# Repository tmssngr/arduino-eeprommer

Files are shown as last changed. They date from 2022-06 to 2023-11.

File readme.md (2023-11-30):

# Arduino-Shield to flash EEPROMs

This is an Arduino shield that can be used to read or flash EEPROMs.
I've successfully flashed 28C16 and 28C64.

## Hardware
The schematic you can find [here](kicad/EPROM-Shield.pdf).
It has been created with KiCad 5.1.12.

The 74'595 shift registers are used to set the address lines A0-A12, /CS, /OE and /WE.
The address lines A13 and A14 for 28C128 or 28C256 are only available through jumpers, so only up to 8kB could be flashed in one row.

The EEPROMs data pins are connected via resistors to the arduino pins D0-D7 to prevent problems if the EEPROM and the Arduino accessing these pins as output.
For those arduino boards that use pins D0 and D1 for serial communication, you can use AD0 and AD1 instead.
In that case omit the resistors to D0 and D1, install those to AD0 and AD1, and change the constants `PIN_D0` and `PIN_D1` at the beginning of the [Eprommer595.ino](arduino/Eprommer595/Eprommer595.ino).

Note, you need to solder the pin headers onto the bottom side (in contrast to the below 3D view).

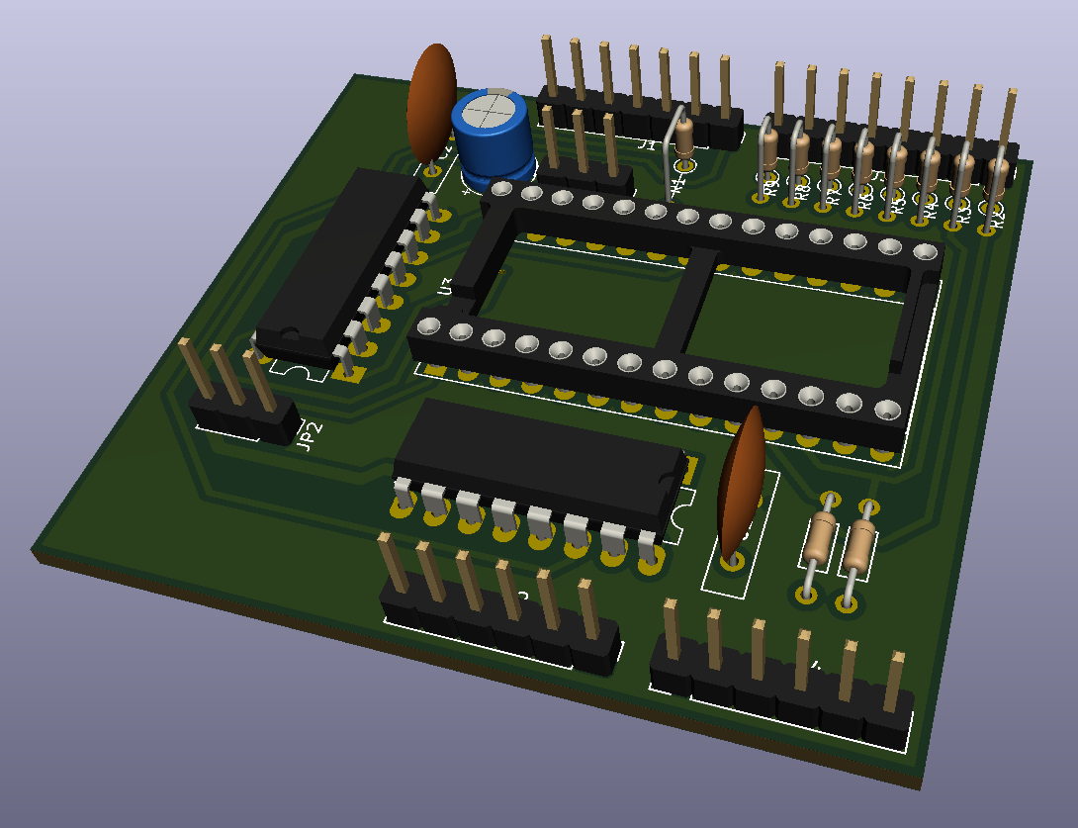
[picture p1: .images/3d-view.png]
3D-View


## Software
For simplicity the data to flash should be provided as array content (see [data_jute6k_video.h](arduino/Eprommer595/data_jute6k_video.h)).
Any output is provided over serial communication (9600 baud).

## Todo
- reserve more space around EEPROM to be able to mount a ZIF socket

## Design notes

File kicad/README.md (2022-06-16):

# EEPROMmer as Arduino Shield
This is my first attempt to create am EEPROMmer in the form of an Arduino shield.

## Alternative Approaches:
- Arduino-Mega-based: https://github.com/bmpc/arduino_eeprom_programmer
- Very good explanation of steps from breadboard: https://www.youtube.com/watch?v=K88pgWhEb1M

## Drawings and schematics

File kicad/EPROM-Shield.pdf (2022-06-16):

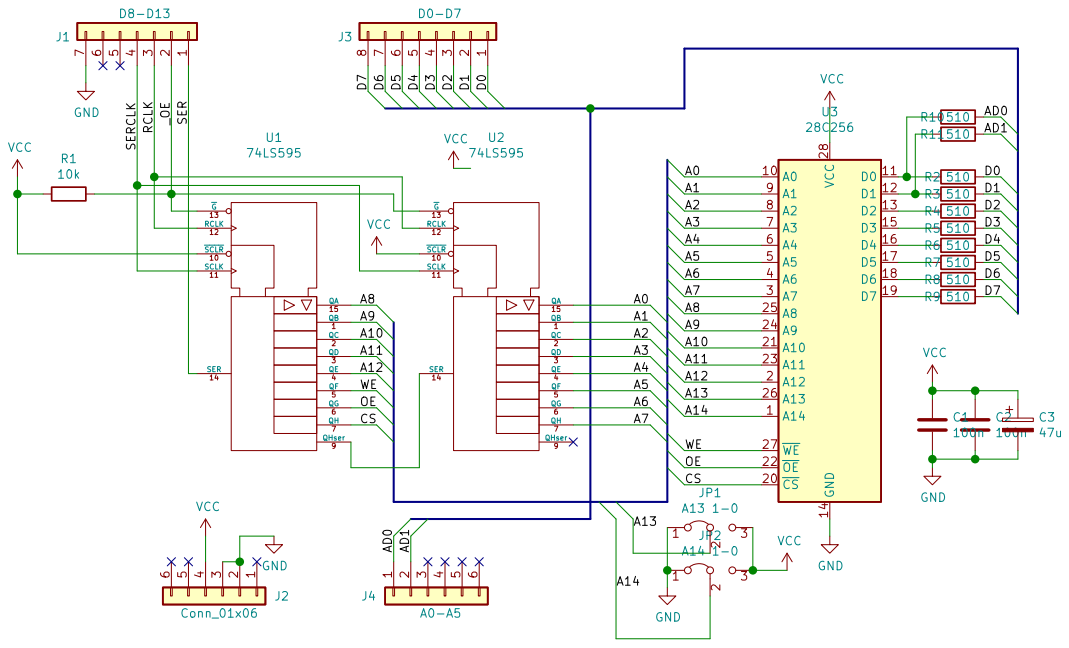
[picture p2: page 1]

Id: 1/1 Title: File: EPROM-Shield.sch Sheet: /

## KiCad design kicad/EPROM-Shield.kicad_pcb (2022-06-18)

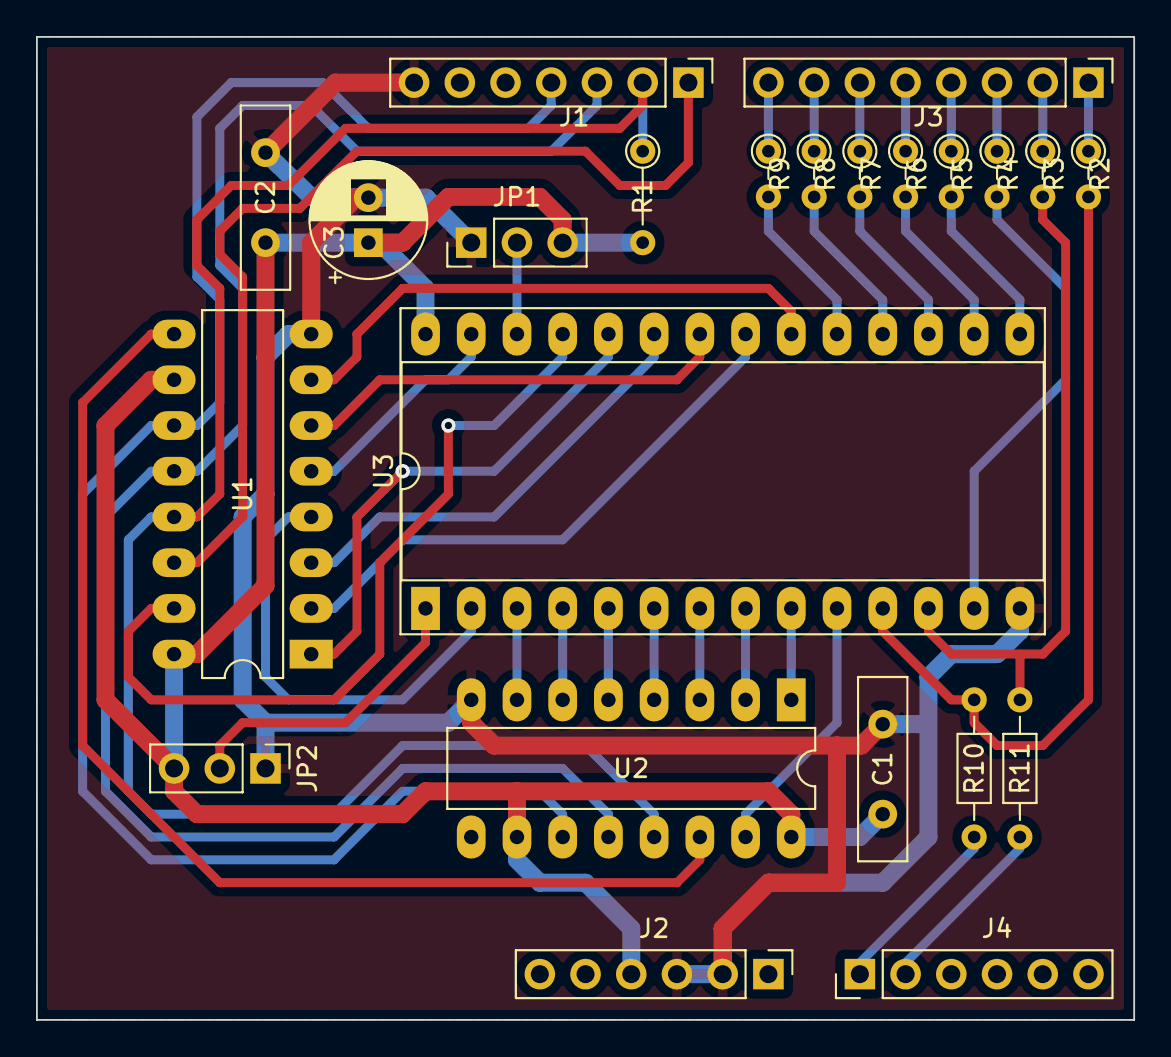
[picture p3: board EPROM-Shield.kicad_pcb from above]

Board: 2 copper layers, 61.0 x 54.6 mm, 23 parts (0 on the bottom side), 43 nets.

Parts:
C1, C2: 100n; C_Disc_D10.0mm_W2.5mm_P5.00mm
C3: 47u; CP_Radial_D6.3mm_P2.50mm
J1: D8-D13; PinHeader_1x07_P2.54mm_Vertical
J2: Conn_01x06; PinHeader_1x06_P2.54mm_Vertical
J3: D0-D7; PinHeader_1x08_P2.54mm_Vertical
J4: A0-A5; PinHeader_1x06_P2.54mm_Vertical
JP1: A13 1-0; PinHeader_1x03_P2.54mm_Vertical
JP2: A14 1-0; PinHeader_1x03_P2.54mm_Vertical
R1: 10k; R_Axial_DIN0204_L3.6mm_D1.6mm_P5.08mm_Vertical
R2, R3, R4, R5, R6, R7, R8, R9: 510; R_Axial_DIN0204_L3.6mm_D1.6mm_P2.54mm_Vertical
R10, R11: 510; R_Axial_DIN0204_L3.6mm_D1.6mm_P7.62mm_Horizontal
U1, U2: 74LS595; DIP-16_W7.62mm_LongPads
U3: 28C256; DIP-28_W15.24mm_Socket_LongPads

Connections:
/A0: U2.15, U3.10
/A1: U2.1, U3.9
/A2: U2.2, U3.8
/A3: U2.3, U3.7
/A4: U2.4, U3.6
/A5: U2.5, U3.5
/A6: U2.6, U3.4
/A7: U2.7, U3.3
/A8: U1.15, U3.25
/A9: U1.1, U3.24
/A10: U1.2, U3.21
/A11: U1.3, U3.23
/A12: U1.4, U3.2
/A13: JP1.2, U3.26
/A14: JP2.2, U3.1
/AD0: J4.1, R10.1
/AD1: J4.2, R11.1
/CS: U1.7, U3.20
/D0: J3.1, R2.1
/D1: J3.2, R3.1
/D2: J3.3, R4.1
/D3: J3.4, R5.1
/D4: J3.5, R6.1
/D5: J3.6, R7.1
/D6: J3.7, R8.1
/D7: J3.8, R9.1
/OE: U1.6, U3.22
/RCLK: J1.3, U1.12, U2.12
/SER: J1.1, U1.14
/SERCLK: J1.4, U1.11, U2.11
/WE: U1.5, U3.27
/_OE: J1.2, R1.1, U1.13, U2.13
GND: C1.2, C2.2, C3.2, J1.7, J2.2, J2.3, JP1.1, JP2.1, U1.8, U2.8, U3.14
unnamed: R4.2, U3.13
unnamed: R5.2, U3.15
unnamed: R6.2, U3.16
unnamed: R7.2, U3.17
unnamed: R8.2, U3.18
unnamed: R9.2, U3.19
unnamed: R2.2, R10.2, U3.11
unnamed: R3.2, R11.2, U3.12
unnamed: U1.9, U2.14
VCC: C1.1, C2.1, C3.1, J2.4, JP1.3, JP2.3, R1.2, U1.10, U1.16, U2.10, U2.16, U3.28

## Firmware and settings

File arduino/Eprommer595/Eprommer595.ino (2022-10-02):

#include "serial_utils.h"
#include "data_jute6k_video.h"
//#include "data_ub8830_jute6k.h"
//#include "data_ub8830_jute6k_modified_keyboard.h"

const uint8_t PIN_SER = 8;
const uint8_t PIN_OE = 9;
const uint8_t PIN_RCLK = 10;
const uint8_t PIN_SERCLK = 11;
const uint8_t PIN_D0 = 0;
const uint8_t PIN_D1 = 1;
const uint8_t PIN_D2 = 2;
const uint8_t PIN_D3 = 3;
const uint8_t PIN_D4 = 4;
const uint8_t PIN_D5 = 5;
const uint8_t PIN_D6 = 6;
const uint8_t PIN_D7 = 7;

const uint8_t DEBUG = 0;

void setup() {
  pinMode(PIN_SER, OUTPUT);
  pinMode(PIN_OE, OUTPUT);
  pinMode(PIN_RCLK, OUTPUT);
  pinMode(PIN_SERCLK, OUTPUT);
  setDataMode(INPUT);
  setAddress_WE_OE_CS(0, 1, 1, 1);

  Serial.begin(9600);
  while (!Serial) {
    // wait
  }

  Serial.println("start" );

  // uncomment the next 2 lines to write and verify the imported DATA array
  //writeData();
  //verifyData();

  printRomContent(0, 0x2000);
}

void loop() {
}

void testWriteRead() {
  for (int i = 0; i < 0x800; i++) {
    write(i, 0xff);
  }

  printRomContent(0, 0x800);
}

uint8_t readData(int address) {
  return pgm_read_byte(DATA + address);
}

void writeData() {
  Serial.println("Writing");

  for (int i = 0; i < DATA_LENGTH; i++) {
    if (i % 16 == 0) {
      if (i > 0) {
        Serial.println();
      }
      serialPrintHex(i, 4);
      Serial.print(" ");
    }

    writeAndVerify(i, readData(i));
  }
}

void verifyData() {
  Serial.println("Verifying");

  int errors = 0;
  for (int i = 0; i < DATA_LENGTH; i++) {
    if (i % 16 == 0) {
      if (i > 0) {
        Serial.println();
      }
      serialPrintHex(i, 4);
    }

    uint8_t readValue = read(i);
    uint8_t expectedValue = readData(i);
    if (readValue != expectedValue) {
      Serial.print(" expected ");
      serialPrintHex(expectedValue, 2);
      Serial.print(" at ");
      serialPrintHex(i, 4);
      Serial.print(", but read ");
      serialPrintHex(readValue, 2);
      Serial.println();
      errors++;
    }

    if (i % 16 == 15 || i + 1 == DATA_LENGTH) {
      Serial.println(" OK");
    }
  }

  if (errors == 0) {
    Serial.println("No errors :)");
  }
  else {
    Serial.print(errors);
    Serial.println(" errors :(");
  }
}

void printRomContent(int start, int end) {
  for (int i = start; i < end; i++) {
    if (i % 16 == 0) {
      if (i > 0) {
        Serial.println();
      }
      serialPrintHex(i, 4);
    }

    Serial.print(" ");

    uint8_t value = read(i);
    serialPrintHex(value, 2);
  }
  Serial.println();
}

void writeAndVerify(uint16_t address, uint8_t value) {
  if (DEBUG == 1) {
    serialPrintHex(address, 4);
    Serial.print(":=");
    serialPrintHex(value, 2);
    Serial.println(">");
  }

  uint8_t existingValue = read(address);
  if (existingValue == value) {
    Serial.print(" ");
    return;
  }

  write(address, value);
  delay(10);

  for (int i = 0; i < 10; i++) {
    uint8_t readValue = read(address);
    if (readValue == value) {
      return;
    }

    Serial.print(".");
  }

  Serial.print("FAILURE at ");
  serialPrintHex(address, 4);
  Serial.print(" - aborting");
  while (true) {
  }
}

void write(uint16_t address, uint8_t value) {
  setAddress_WE_OE_CS(address, 1, 1, 1);
  // In the XL1816 the write cycle is initiated by applying 
  // a logical 0 to both /WE adn /CE while /OE is logical 1.
  // The address inputs are latched into the device on the 
  // falling edge of /WE or /CE (whichever is last) to specify 
  // the address that is to be written.
  setAddress_WE_OE_CS(address, 0, 1, 0);
  setDataMode(OUTPUT);
  writeByte(value);
  // Data on the I/O pins is then latched into the device by
  // bringing either /WE or /CE high.
  setAddress_WE_OE_CS(address, 1, 1, 1);
  // Once the data is latched, the XL2816 will automatically 
  // erase the selected byte and write the new data in less
  // than 10ms.
  // The system is therefore freed to proceed with other operations 
  // while the XL2816 autnomously executes its internal write cycle.
  // The I/O pins will be in a high impedance state while the write
  // operation is in progress with the exception of I/O7 if a read 
  // command is asserted.
  setDataMode(INPUT);
}

void writeByte(uint8_t value) {
  digitalWrite(PIN_D0, (value & 1 << 0) != 0);
  digitalWrite(PIN_D1, (value & 1 << 1) != 0);
  digitalWrite(PIN_D2, (value & 1 << 2) != 0);
  digitalWrite(PIN_D3, (value & 1 << 3) != 0);
  digitalWrite(PIN_D4, (value & 1 << 4) != 0);
  digitalWrite(PIN_D5, (value & 1 << 5) != 0);
  digitalWrite(PIN_D6, (value & 1 << 6) != 0);
  digitalWrite(PIN_D7, (value & 1 << 7) != 0);
}

uint8_t read(uint16_t address) {
  setDataMode(INPUT);
  setAddress_WE_OE_CS(address, 1, 1, 1);
  setAddress_WE_OE_CS(address, 1, 0, 0);
  uint8_t value = readByte();
  setAddress_WE_OE_CS(address, 1, 1, 1);
  return value;
}

uint8_t readByte() {
  return digitalRead(PIN_D0) << 0
       | digitalRead(PIN_D1) << 1
       | digitalRead(PIN_D2) << 2
       | digitalRead(PIN_D3) << 3
       | digitalRead(PIN_D4) << 4
       | digitalRead(PIN_D5) << 5
       | digitalRead(PIN_D6) << 6
       | digitalRead(PIN_D7) << 7;
}

void setDataMode(uint8_t mode) {
  pinMode(PIN_D0, mode);
  pinMode(PIN_D1, mode);
  pinMode(PIN_D2, mode);
  pinMode(PIN_D3, mode);
  pinMode(PIN_D4, mode);
  pinMode(PIN_D5, mode);
  pinMode(PIN_D6, mode);
  pinMode(PIN_D7, mode);
}

void setAddress_WE_OE_CS(uint16_t address, uint8_t we, uint8_t oe, uint8_t cs) {
  uint16_t value = address & 0x1FFF;
  if (we != 0) {
    value |= 0x2000;
  }
  if (oe != 0) {
    value |= 0x4000;
  }
  if (cs != 0) {
    value |= 0x8000;
  }
  shift16(value);
}

void shift16(uint16_t value) {
  if (DEBUG == 1) {
    Serial.print("value = ");
    Serial.println(value, BIN);
  }

  // the serial registers are connected in the wrong order
  // so we need to switch here the bytes

  digitalWrite(PIN_OE, 0);
  digitalWrite(PIN_RCLK, 0);
  digitalWrite(PIN_SERCLK, 0);

  shift8(value);
  shift8(value >> 8);

  digitalWrite(PIN_RCLK, 1);
  delayMicroseconds(1);
  digitalWrite(PIN_RCLK, 0);
  delayMicroseconds(1);
  digitalWrite(PIN_OE, 0);
  delayMicroseconds(1);
}

void shift8(uint16_t value) {
  for (int i = 0; i < 8; i++) {
    const uint8_t bit = (value & 0x80) != 0 ? 1 : 0;

    if (DEBUG == 1) {
      Serial.print(i);
      Serial.print("=");
      Serial.println(bit);
    }

    digitalWrite(PIN_SER, bit);
    delayMicroseconds(1);
    digitalWrite(PIN_SERCLK, 1);
    delayMicroseconds(1);
    digitalWrite(PIN_SERCLK, 0);
    delayMicroseconds(1);

    value <<= 1;
  }
}

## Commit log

2022-06-16 initial import
    [EPROM-Shield-B_Cu.gbl, EPROM-Shield-B_Mask.gbs, EPROM-Shield-B_Paste.gbp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]
2022-06-18 change footprint of EEPROM to one with socket
    [EPROM-Shield.kicad_pcb, EPROM-Shield.sch]
